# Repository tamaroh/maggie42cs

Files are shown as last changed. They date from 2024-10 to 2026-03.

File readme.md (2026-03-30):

# Maggie42cs

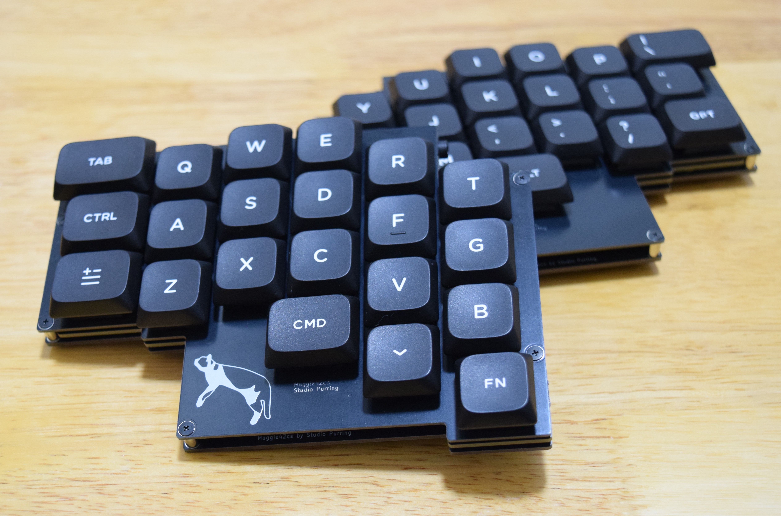
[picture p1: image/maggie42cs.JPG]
top image

Maggie42csは42キー分割型の自作キーボードです。
- 左右対称カラムスタッガード
- Alice配列に似た、自然にハの字に手が配置されるデザイン
- MX Cherry 互換スイッチ、Kailh Choc v1, v2スイッチの3種に対応
- Extension キーはキーキャップセットで揃いやすい1.25U, 1.5Uに対応

## 必要なもの

| 部品名称 | 数量（両手分） | 備考 | 主な購入先 |
| ---  | --- | --- | --- |
| PCB | 1 | サポートを折って左右に分けます | |
| トッププレート | 2 | 猫のシルエットがあるのが左側 | |
| ボトムプレート | 2 | 左右の差はありません | |
| ネジ | 24 | M2 | |
| 丸スペーサー | 12 | 5mm or 7.5mm | |
| ゴム足 | 8 | | |
| スイッチソケット | 42 | Cherry MX / Kailh choc 対応のもの | [TALP KEYBOARD](https://shop.talpkeyboard.com) など |
| メカニカルスイッチ | 42 | Cherry MX / Kailh choc V1 / V2 対応* | [遊舎工房](https://shop.yushakobo.jp/collections/all-switches) など |
| キーキャップ | 1U x 33, 1.25U x 7, 1.5U x 2 | スイッチに対応したもの | [遊舎工房](https://shop.yushakobo.jp/collections/keycaps) など |
| TRSコネクター | 2 | PJ-399B-6A | [LCSC](https://www.lcsc.com/) など |
| 3.5mmオーディオケーブル | 1 | TRRS（4極）またはTRS（3極） | [TALP KEYBOARD](https://shop.talpkeyboard.com) など |
| USBケーブル | 1 | 機器側がTypeCのもの | 家電量販店など |

## 使用する工具など

- はんだ付け工具
  - こて、こて台、こて先クリーナー、はんだ線など
- 精密ドライバー

## あると便利なもの

- ピンセット
- キースイッチプラー
- キーキャッププラー
- はんだ吸い取り線または吸い取り器
- 絶縁耐熱テープ
- 
## 製作手順

1. PCBのサポート部分を折り取ります。折った部分のデコボコが気になる場合はやすりなどで削ってください。
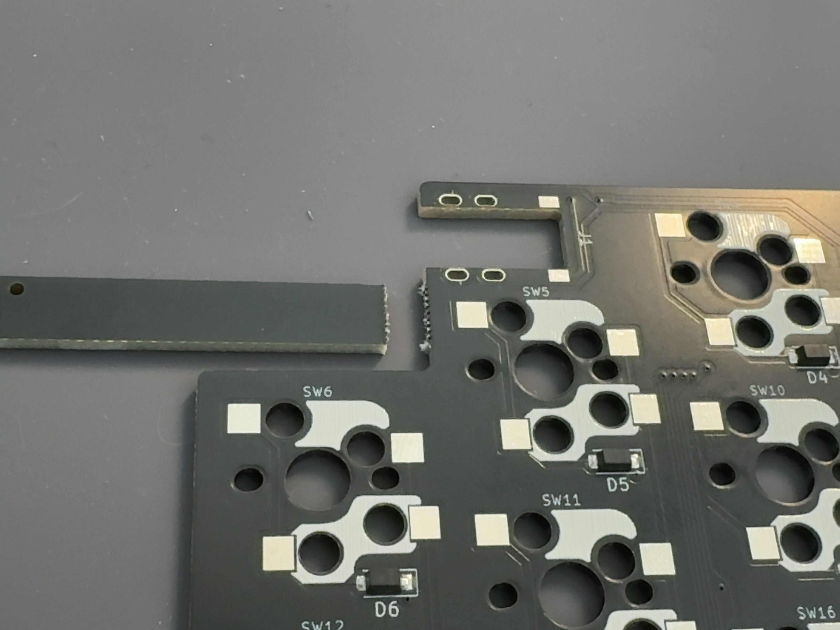
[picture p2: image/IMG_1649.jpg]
pcb
   
1. ソケットをはんだ付けします。  
   MXスイッチ用のソケットは上側、Chocスイッチ用のソケットは下側に設置します。  
   印刷に合わせて、スイッチの穴を塞がないようにします。
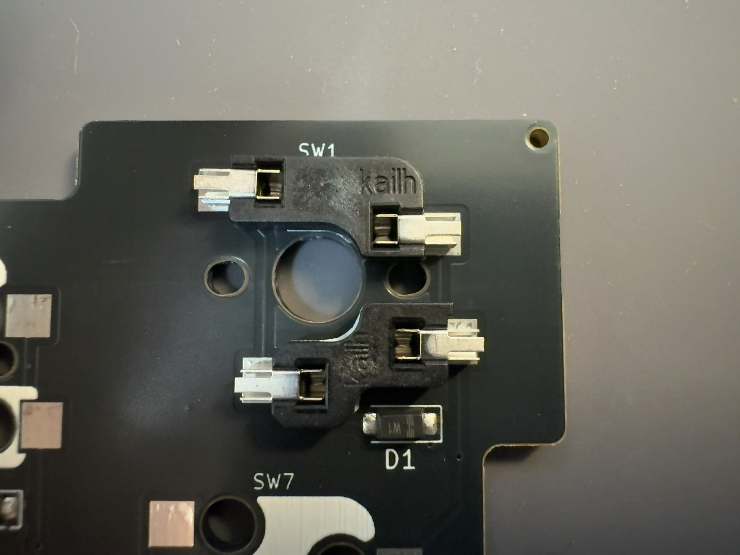
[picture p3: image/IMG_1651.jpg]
socket
   
1. TRSコネクターをはんだ付けします。  
   ずれやすいのでテープなどで固定してください。  
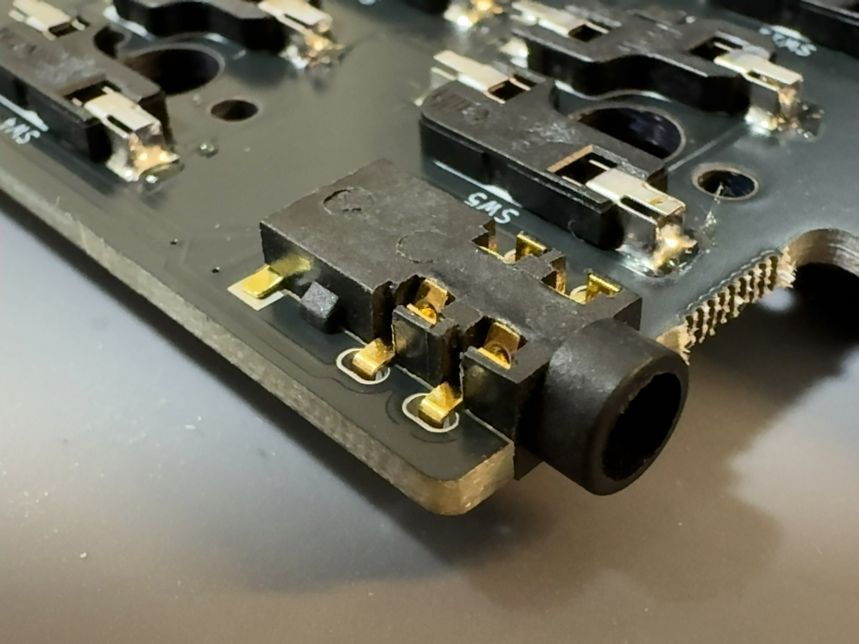
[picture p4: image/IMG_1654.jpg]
TRRS
   
1. ファームウェアのファイル（.uf2）をダウンロードします。  
   https://github.com/tamaroh/maggie42cs/releases/tag/V2.0.2
1. （片側ずつ両方とも）USBケーブルを接続して、以下のいずれかの方法で `RPI-RP2` リムーバブルドライブをマウントさせます。
   1. BOOTSELボタンを押しながら、USBケーブルを接続します。
   1. USBケーブルを接続してから、BOOTSELボタンを押しながらRESETボタンを押します。
   1. 左側はTABキー、右側はYキーを押したままUSBケーブルを接続します（キースイッチ装着済みの場合）。
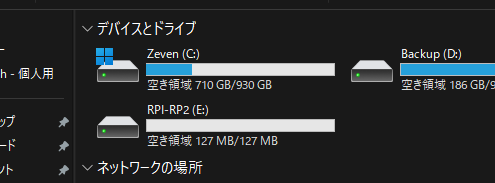
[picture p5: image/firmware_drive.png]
RPI-RP2 drive
   
1. （片側ずつ両方とも）マウントされた `RPI-RP2` ドライブ内にファームウェアのファイルをコピーして保存します。
   自動的にマウントが解除され、キーボードが再起動します。
   再起動したら、一度USBケーブルを抜いてください。
1. キースイッチを数個、先にキープレートに差し込みます。キープレートの表裏は印字以外にはありません。
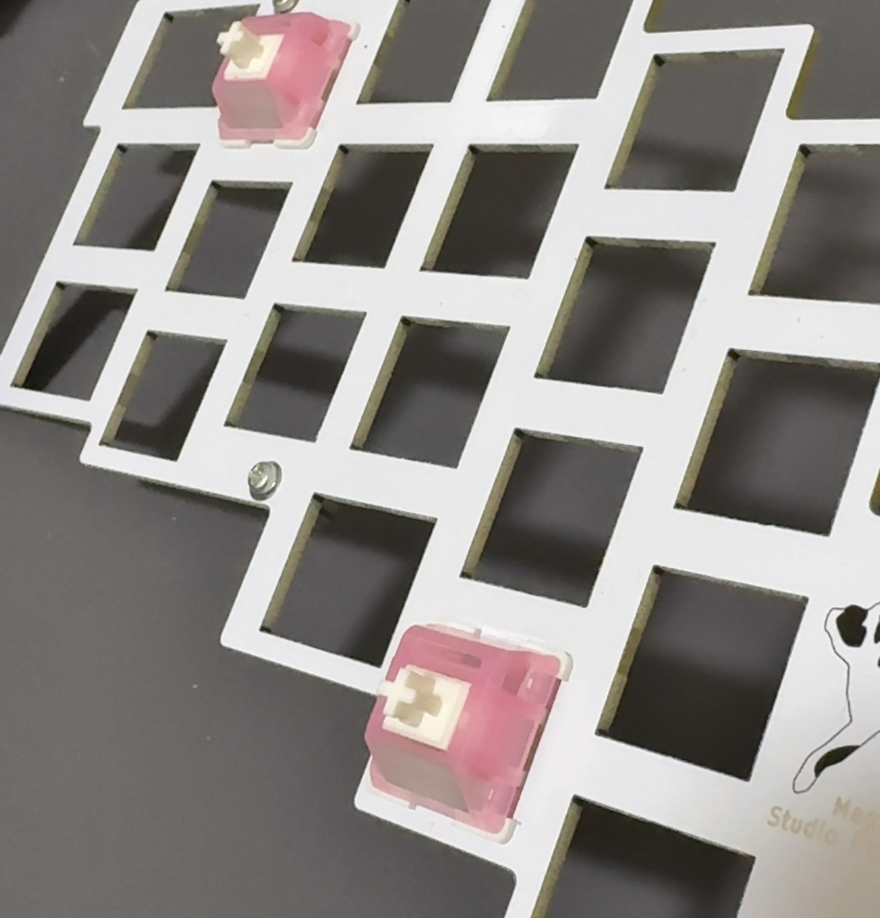
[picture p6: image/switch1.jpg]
switch1
   
1. スイッチのピンがソケットに合うように上からまっすぐ抑え、基板と接続して位置を合わせます。
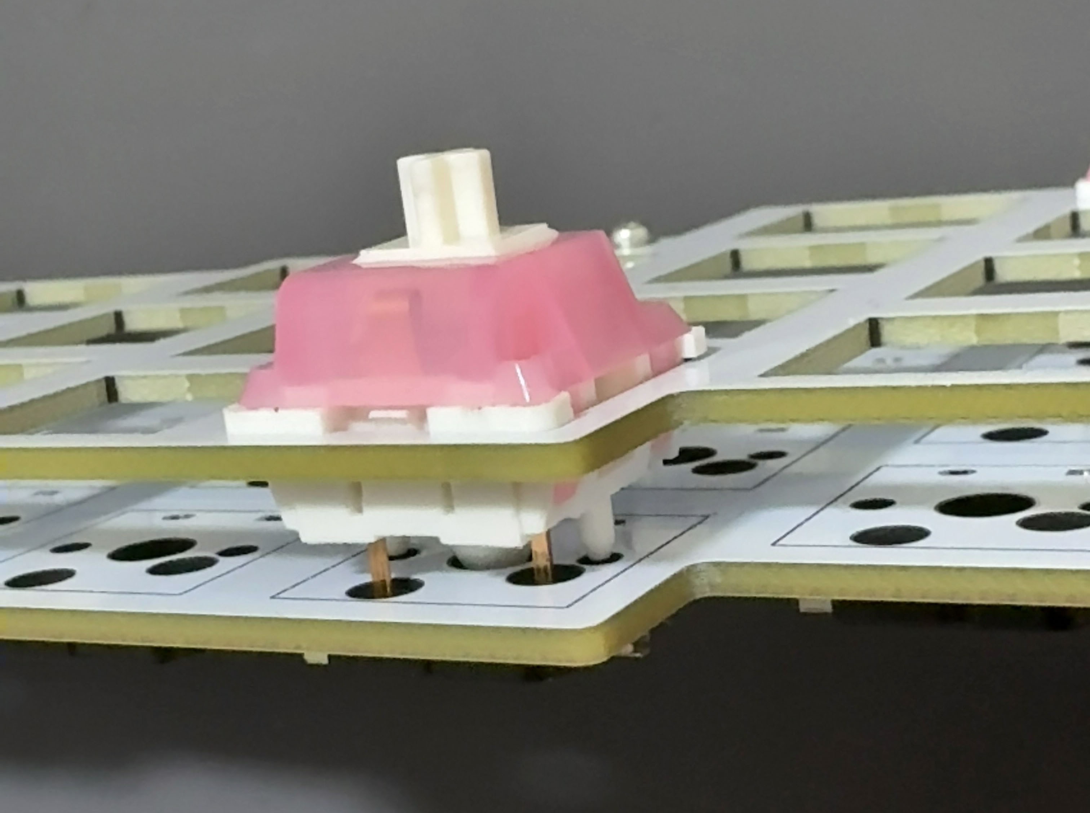
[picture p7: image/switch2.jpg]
switch2
   
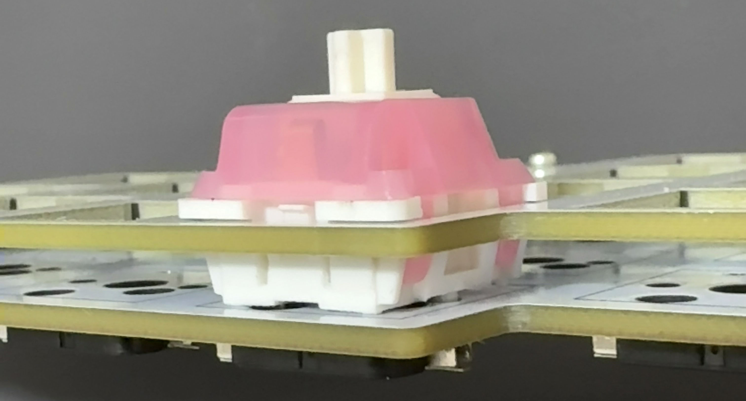
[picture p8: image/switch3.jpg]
switch3
   
1. 残りのスイッチを差し込みます。ソケットとスイッチを指で挟み込むようにして、ソケットに確実に差し込みます。
1. 基板を裏返し、ソケットからスイッチの端子の先端が見えることを確認してください。見えない場合はスイッチのピンが曲がっているか、ソケットの不良です。
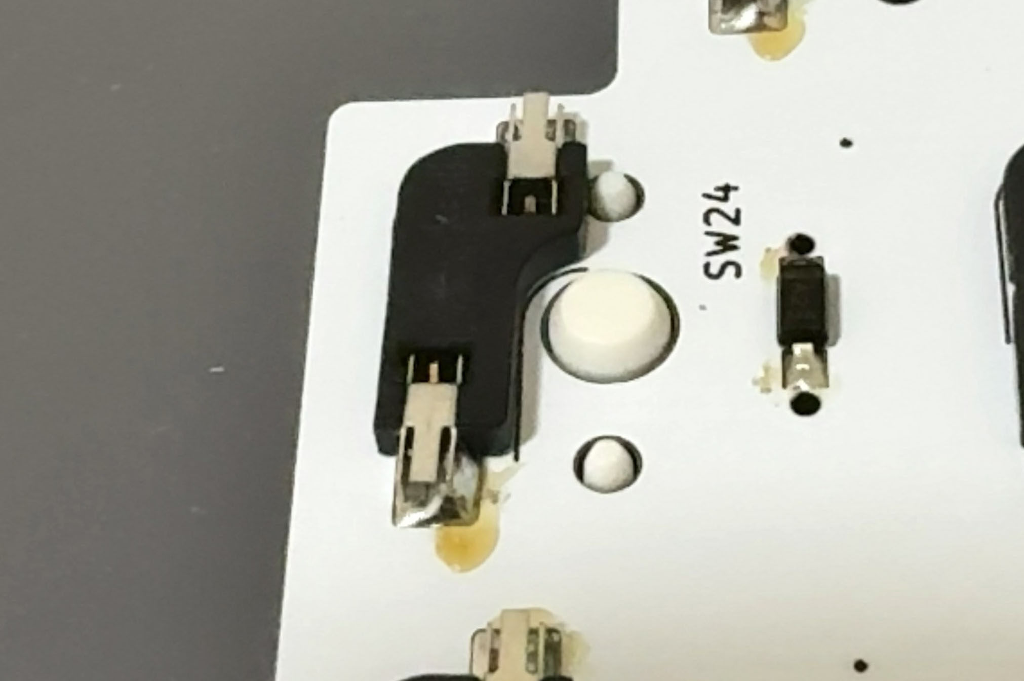
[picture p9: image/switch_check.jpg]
switch check
   
1. ネジとスペーサーをトッププレートにネジ止めします。(片側6箇所) 
1. ボトムプレートをネジ止めし、ゴム足を取り付けます。
1. キーキャップを取り付けます。
1. TRRSケーブルを接続して、できあがり

## キーマップを変更する

Maggie42は[Remap](https://remap-keys.app)によるキーマップ変更に対応しています。  
ハードウェア接続のあとJSONファイルを要求される場合は[ファームウェアと同じ場所](https://github.com/tamaroh/maggie42cs/releases/tag/V2.0.2)からダウンロードして使用してください。

## 注意事項

- 必要な手順や部品の種類・数はアップデートによって変更になる場合があります。
- 本ビルドガイドの写真の一部は製品と異なる場合があります。

## 実装の差異について

キーケット2026にて販売した一部のキットは、製作の時期により差異があります。
- 4極の3.5mmコネクターを使用しています（はんだ実装済みです）。TRS（3極）ケーブルではなくTRRS（4極）ケーブルが必要です。
- 左右でPCBの印字の色が異なります。
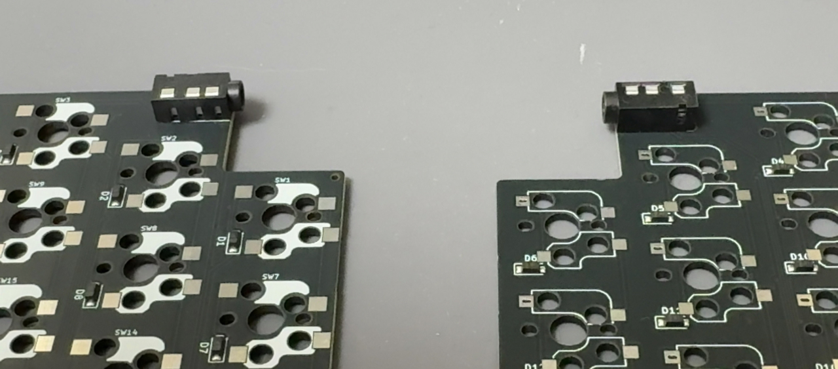
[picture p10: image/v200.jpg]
v200
  
- 手順通りのファームウェアとは異なります。書き込み済みで販売いたしましたが、再度セットアップする場合は[V2.0.0のファームウェア](https://github.com/tamaroh/maggie42cs/releases/tag/V2.0.0)を使用してください。
- Remapにアクセスした際は「maggie42csv2」と表示されます。

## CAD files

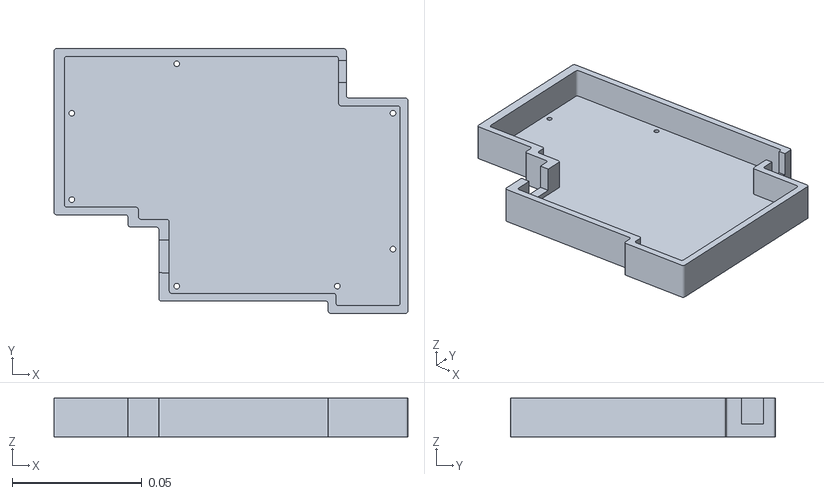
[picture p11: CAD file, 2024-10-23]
case/maggie42cs_v2_case.stl
0.137 x 0.102 x 0.015

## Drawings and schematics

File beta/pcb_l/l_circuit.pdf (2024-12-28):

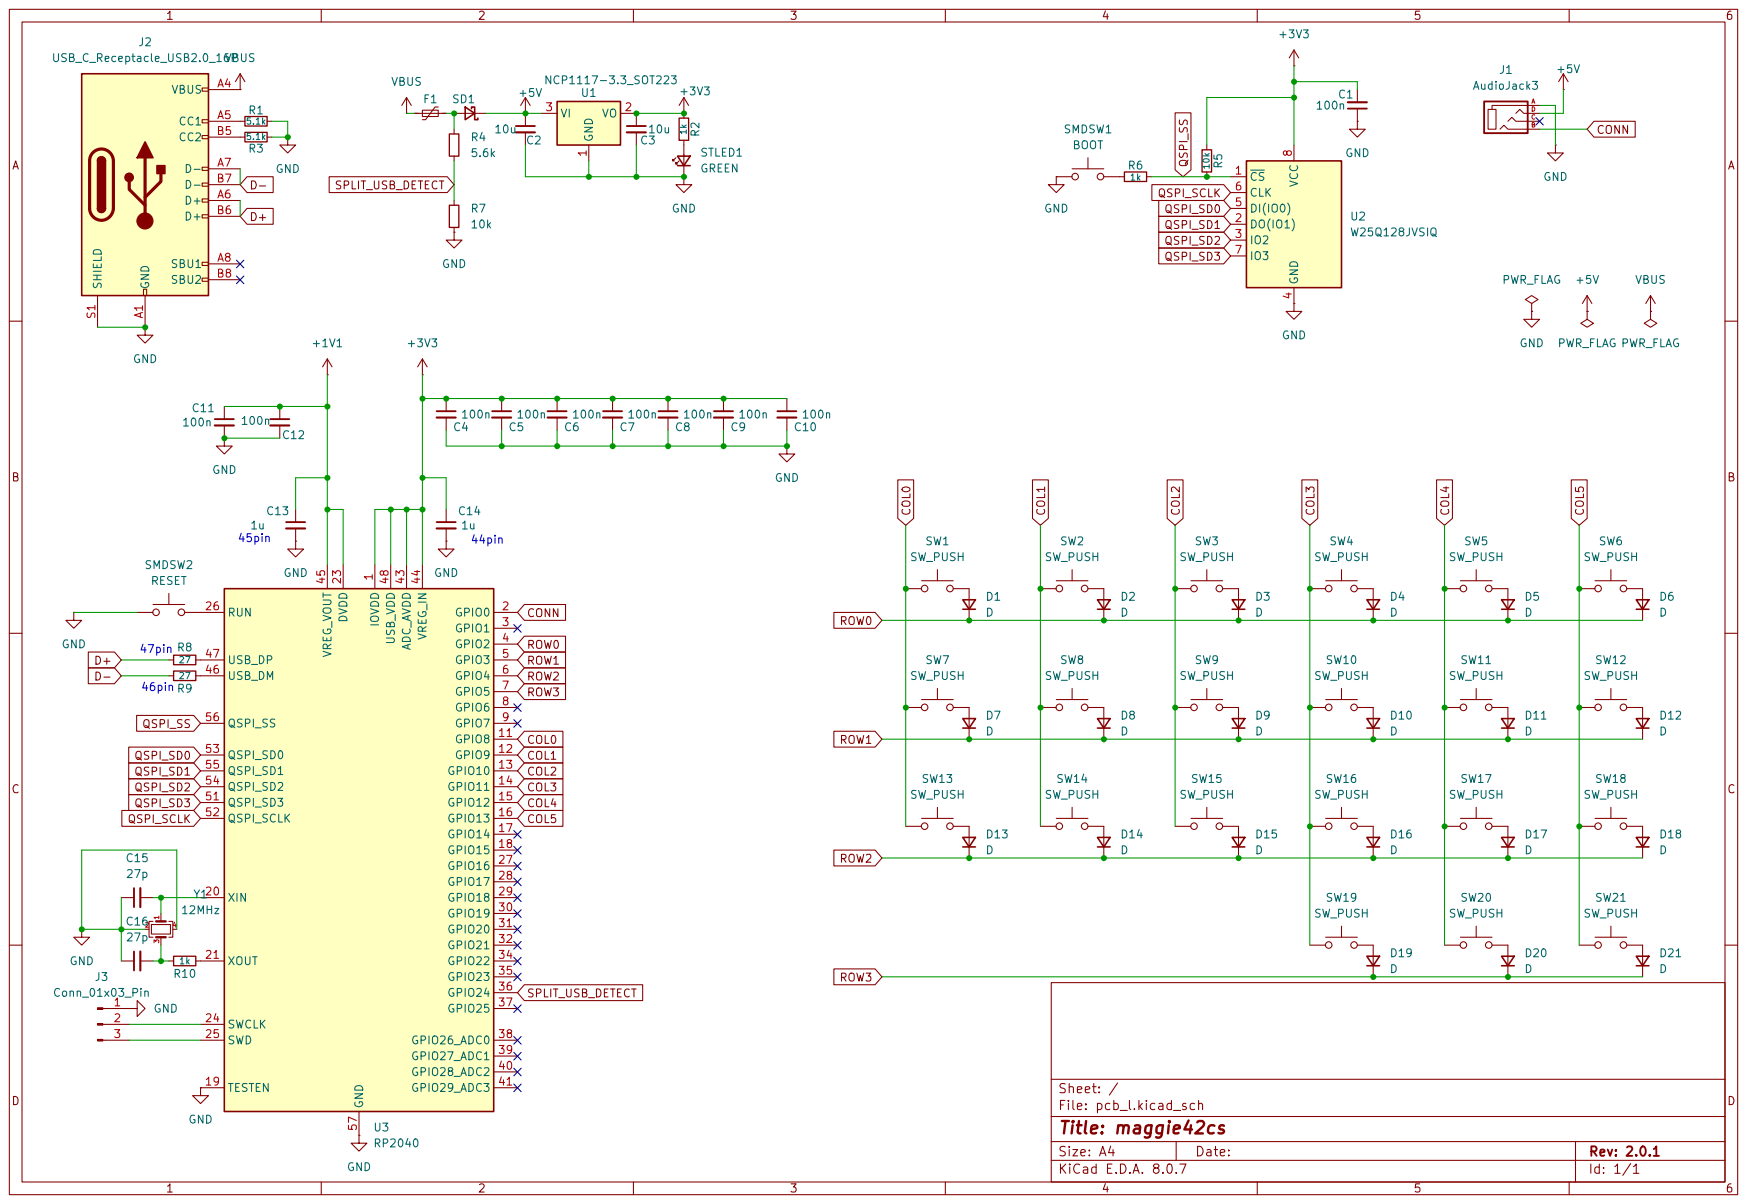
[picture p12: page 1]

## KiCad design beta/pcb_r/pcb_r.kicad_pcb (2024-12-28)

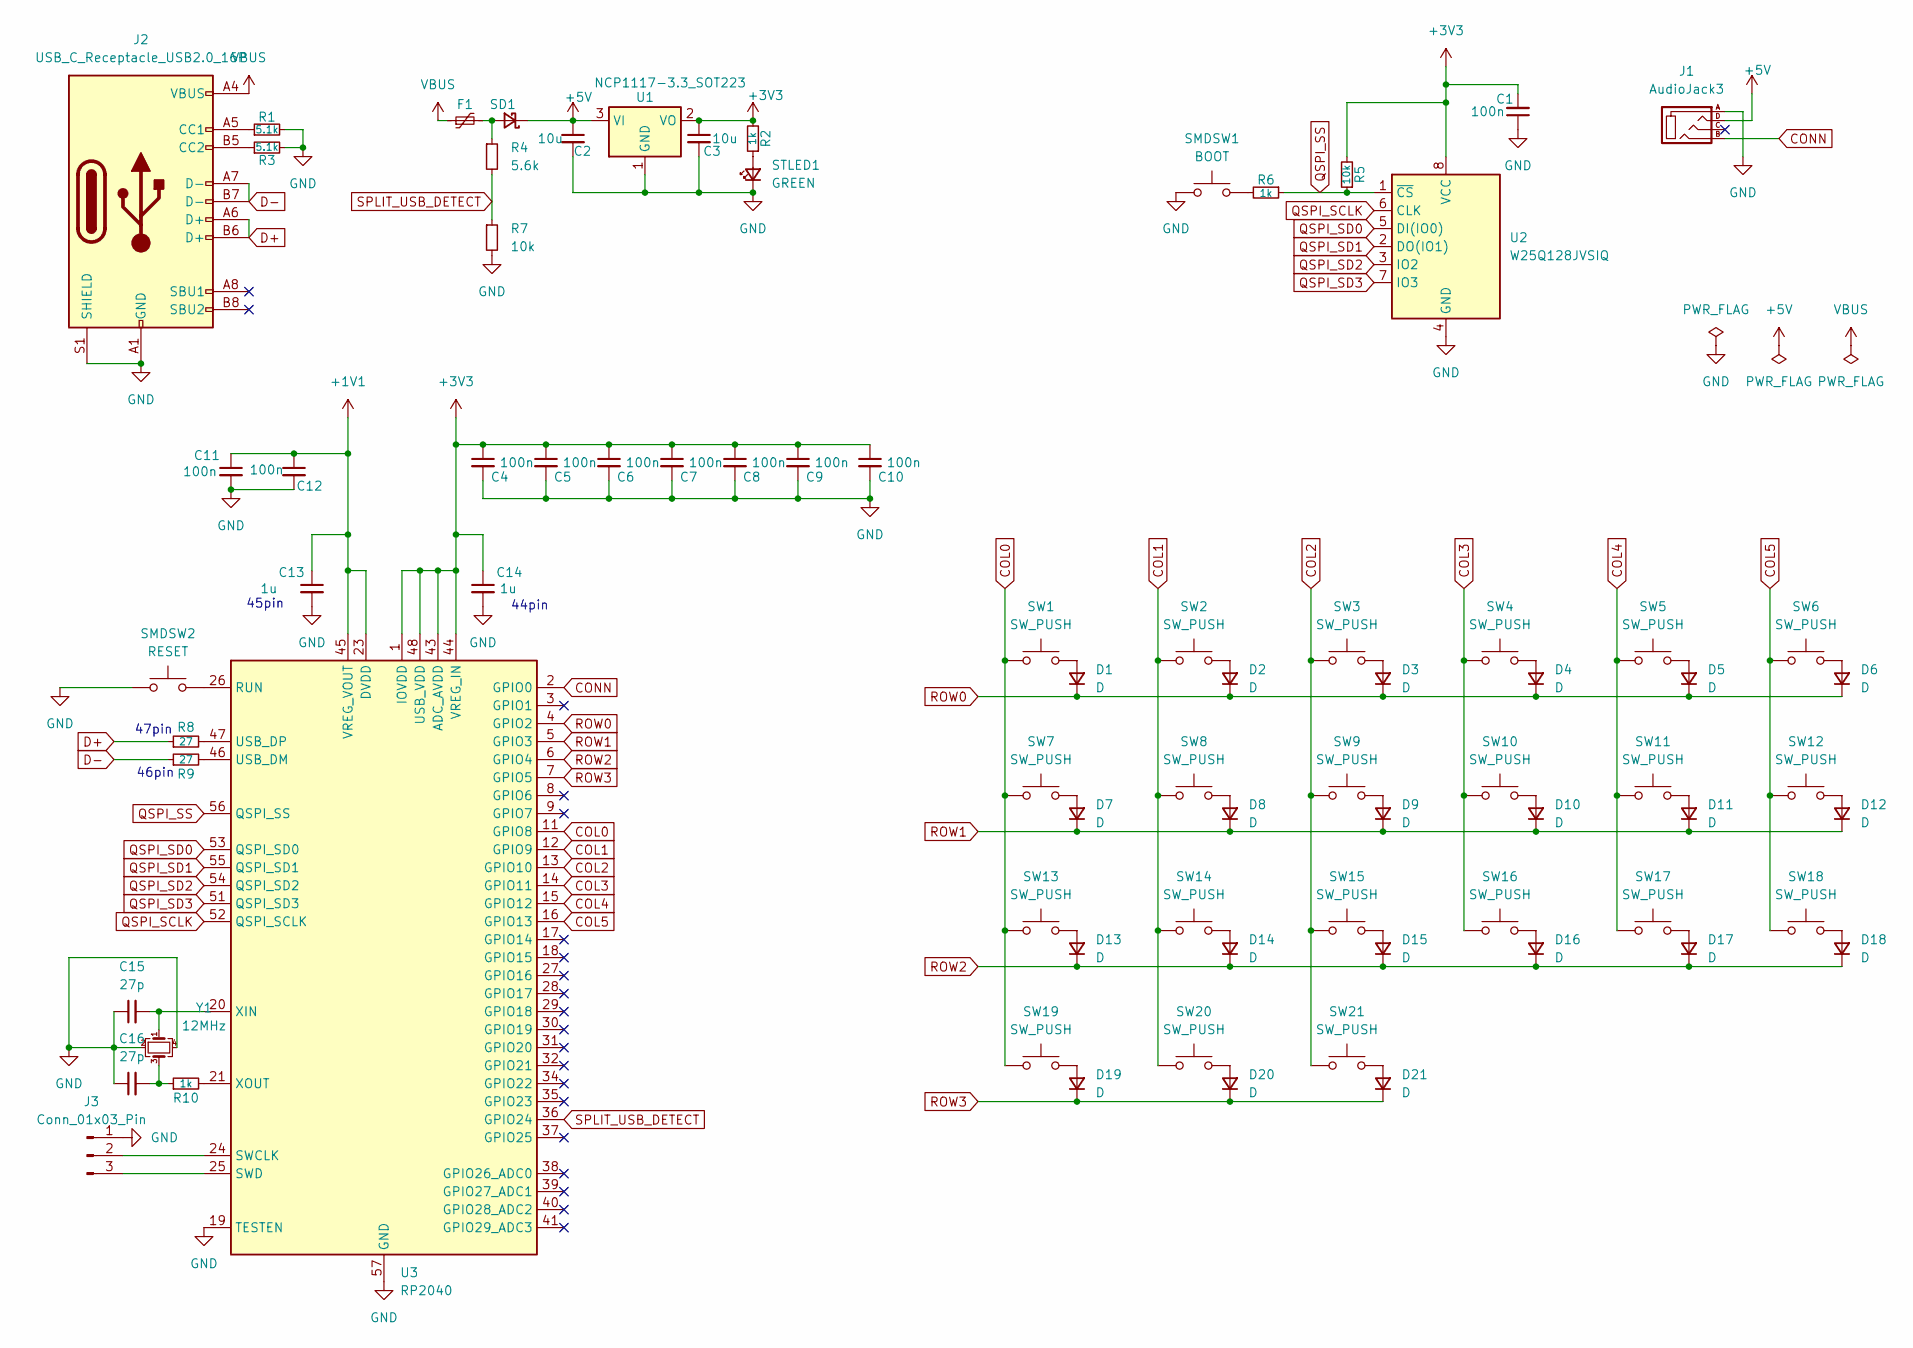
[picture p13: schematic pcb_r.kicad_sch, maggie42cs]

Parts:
C1, C4, C5, C6, C7, C8, C9, C10, C11, C12: 100n; C_0402_1005Metric; LCSC C1525
C2, C3: 10u; C_0402_1005Metric; LCSC C15525
C13, C14: 1u; C_0402_1005Metric; LCSC C52923
C15, C16: 27p; C_0402_1005Metric; LCSC C1557
D1, D2, D3, D4, D5, D6, D7, D8, D9, D10, D11, D12, D13, D14, D15, D16, D17, D18, D19, D20, D21: D; D_SOD-123; LCSC C81598
F1: Fuse_0603_1608Metric; LCSC C2757930
J1: AudioJack3; MJ-4PP-9_1side; LCSC C22459514
J2: USB_C_Receptacle_USB2.0_16P; USB_C_Receptacle_HRO_TYPE-C-31-M-12; LCSC C165948
J3: Conn_01x03_Pin; PinHeader_1x03_P1.27mm_Vertical
R1, R3: 5.1k; R_0402_1005Metric; LCSC C25905
R2, R6, R10: 1k; R_0402_1005Metric; LCSC C11702
R4: 5.6k; R_0402_1005Metric; LCSC C25908
R5, R7: 10k; R_0402_1005Metric; LCSC C25744
R8, R9: 27; R_0402_1005Metric; LCSC C25100
SD1: D_SOD-123; LCSC C8598
SMDSW1: BOOT; TS-1088R-02026; LCSC C455280
SMDSW2: RESET; TS-1088R-02026; LCSC C455280
STLED1: GREEN; LED_0402_1005Metric; LCSC C130723
SW1, SW2, SW3, SW4, SW5, SW7, SW8, SW9, SW10, SW11, SW12, SW13, SW14, SW15, SW16, SW17, SW20: SW_PUSH; keyswitch_cherrymx_choc12_hotswap_1u
SW6: SW_PUSH; keyswitch_cherrymx_choc12_hotswap_1.5u
SW18, SW19, SW21: SW_PUSH; keyswitch_cherrymx_choc12_hotswap_1.25u
U1: NCP1117-3.3_SOT223; SOT-223-3_TabPin2; LCSC C347222
U2: W25Q128JVSIQ; SOIC-8W_5.3x5.3mm_P1.27mm; LCSC C97521
U3: RP2040; QFN-56-1EP_7x7mm_P0.4mm_EP3.2x3.2mm; LCSC C2040
Y1: 12MHz; Crystal_SMD_SeikoEpson_TSX3225-4Pin_3.2x2.5mm; LCSC C91749

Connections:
+1V1: C11.1, C12.1, C13.1, U3.23 (DVDD), U3.45 (VREG_VOUT), U3.50 (DVDD)
+3V3: C1.2, C3.1, C4.1, C5.1, C6.1, C7.1, C8.1, C9.1, C10.1, C14.1, R2.2, R5.2, U1.2 (VO), U2.8 (VCC), U3.1 (IOVDD), U3.10 (IOVDD), U3.22 (IOVDD), U3.33 (IOVDD), U3.42 (IOVDD), U3.43 (ADC_AVDD), U3.44 (VREG_IN), U3.48 (USB_VDD), U3.49 (IOVDD)
+5V: C2.1, J1.D, SD1.1 (K), U1.3 (VI)
COL0: SW1.1, SW7.1, SW13.1, SW19.1, U3.11 (GPIO8)
COL1: SW2.1, SW8.1, SW14.1, SW20.1, U3.12 (GPIO9)
COL2: SW3.1, SW9.1, SW15.1, SW21.1, U3.13 (GPIO10)
COL3: SW4.1, SW10.1, SW16.1, U3.14 (GPIO11)
COL4: SW5.1, SW11.1, SW17.1, U3.15 (GPIO12)
COL5: SW6.1, SW12.1, SW18.1, U3.16 (GPIO13)
CONN: J1.B, U3.2 (GPIO0)
D+: J2.A6 (D+), J2.B6 (D+), R8.1
D-: J2.A7 (D-), J2.B7 (D-), R9.1
GND: C1.1, C2.2, C3.2, C4.2, C5.2, C6.2, C7.2, C8.2, C9.2, C10.2, C11.2, C12.2, C13.2, C14.2, C15.1, C16.1, J1.A, J2.A1 (GND), J2.A12 (GND), J2.B1 (GND), J2.B12 (GND), J2.S1 (SHIELD), J3.1, R1.2, R3.2, R7.2, SMDSW1.1, SMDSW2.1, STLED1.1 (K), U1.1 (GND), U2.4 (GND), U3.19 (TESTEN), U3.57 (GND), Y1.2, Y1.4
unnamed: C16.2, R10.1, Y1.3
unnamed: D1.2 (A), SW1.2
unnamed: D2.2 (A), SW2.2
unnamed: D3.2 (A), SW3.2
unnamed: D4.2 (A), SW4.2
unnamed: D5.2 (A), SW5.2
unnamed: D6.2 (A), SW6.2
unnamed: D7.2 (A), SW7.2
unnamed: D8.2 (A), SW8.2
unnamed: D9.2 (A), SW9.2
unnamed: D10.2 (A), SW10.2
unnamed: D11.2 (A), SW11.2
unnamed: D12.2 (A), SW12.2
unnamed: D13.2 (A), SW13.2
unnamed: D14.2 (A), SW14.2
unnamed: D15.2 (A), SW15.2
unnamed: D16.2 (A), SW16.2
unnamed: D17.2 (A), SW17.2
unnamed: D18.2 (A), SW18.2
unnamed: D19.2 (A), SW19.2
unnamed: D20.2 (A), SW20.2
unnamed: D21.2 (A), SW21.2
unnamed: J2.A5 (CC1), R1.1
unnamed: J2.B5 (CC2), R3.1
unnamed: J3.2, U3.24 (SWCLK)
unnamed: J3.3, U3.25 (SWD)
unnamed: R6.2, SMDSW1.2
unnamed: F1.2, R4.1, SD1.2 (A)
unnamed: R2.1, STLED1.2 (A)
unnamed: SMDSW2.2, U3.26 (RUN)
unnamed: R9.2, U3.46 (USB_DM)
unnamed: R8.2, U3.47 (USB_DP)
unnamed: C15.2, U3.20 (XIN), Y1.1
unnamed: R10.2, U3.21 (XOUT)
QSPI_SCLK: U2.6 (CLK), U3.52 (QSPI_SCLK)
QSPI_SD0: U2.5 (DI(IO0)), U3.53 (QSPI_SD0)
QSPI_SD1: U2.2 (DO(IO1)), U3.55 (QSPI_SD1)
QSPI_SD2: U2.3 (IO2), U3.54 (QSPI_SD2)
QSPI_SD3: U2.7 (IO3), U3.51 (QSPI_SD3)
QSPI_SS: R5.1, R6.1, U2.1 (~CS), U3.56 (QSPI_SS)
ROW0: D1.1 (K), D2.1 (K), D3.1 (K), D4.1 (K), D5.1 (K), D6.1 (K), U3.4 (GPIO2)
ROW1: D7.1 (K), D8.1 (K), D9.1 (K), D10.1 (K), D11.1 (K), D12.1 (K), U3.5 (GPIO3)
ROW2: D13.1 (K), D14.1 (K), D15.1 (K), D16.1 (K), D17.1 (K), D18.1 (K), U3.6 (GPIO4)
ROW3: D19.1 (K), D20.1 (K), D21.1 (K), U3.7 (GPIO5)
SPLIT_USB_DETECT: R4.2, R7.1, U3.36 (GPIO24)
VBUS: F1.1, J2.A4 (VBUS), J2.A9 (VBUS), J2.B4 (VBUS), J2.B9 (VBUS)

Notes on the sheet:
47pin
45pin
44pin
46pin

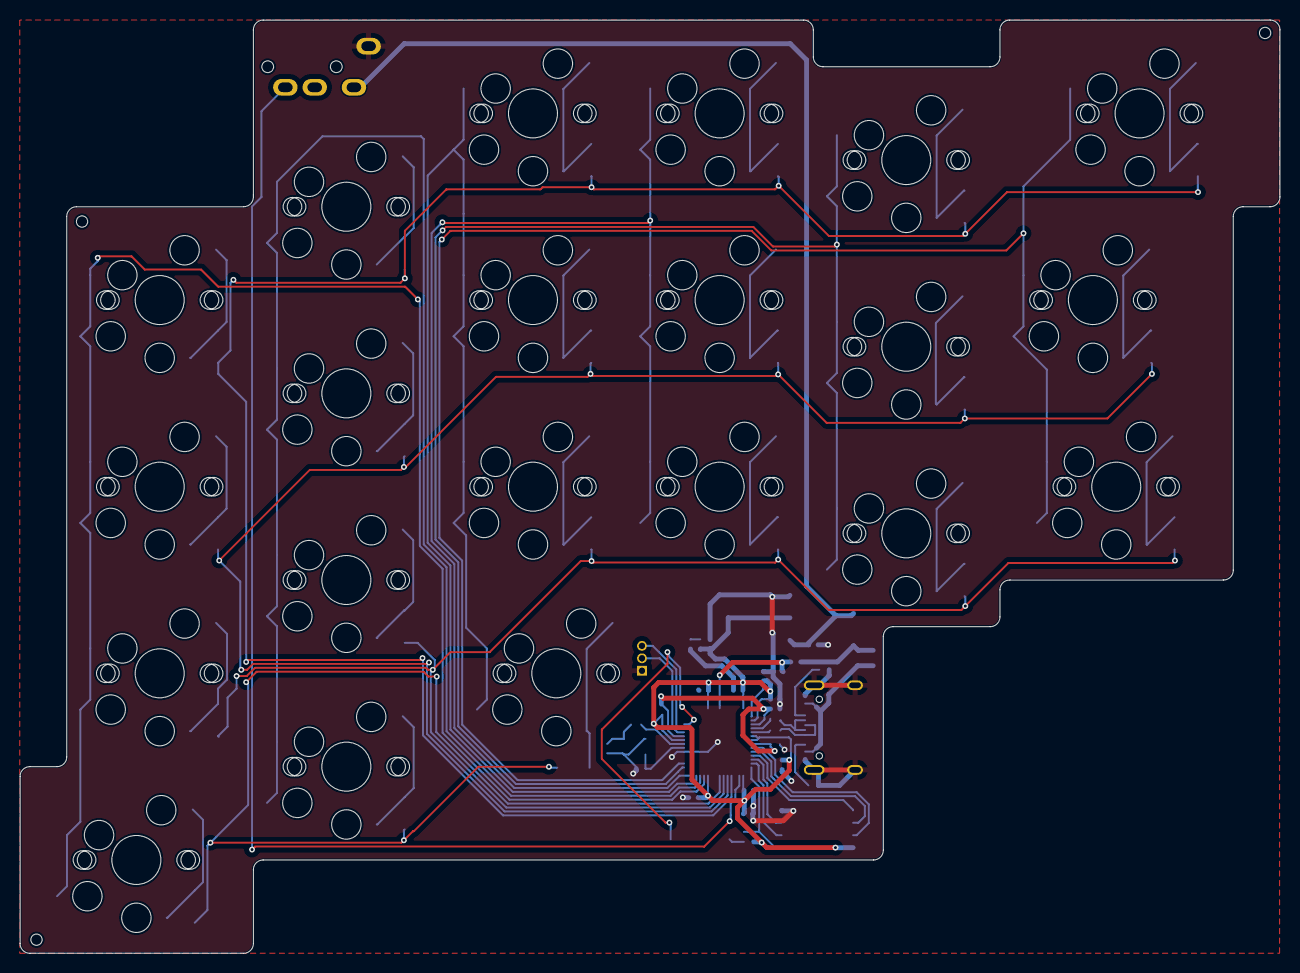
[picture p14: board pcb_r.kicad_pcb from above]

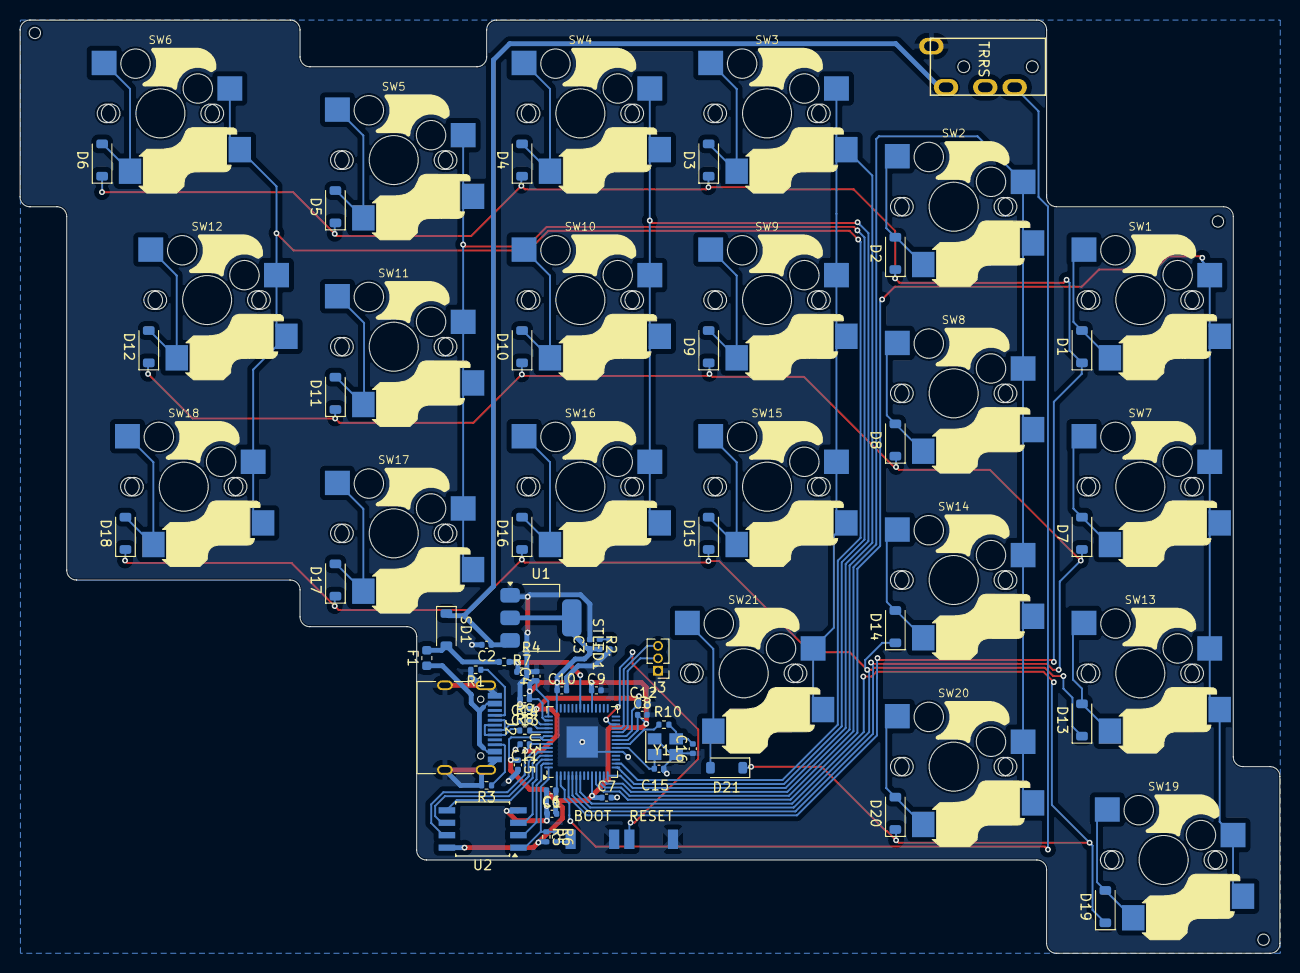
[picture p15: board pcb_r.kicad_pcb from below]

Board: 2 copper layers, 128.6 x 95.2 mm, 80 parts (80 on the bottom side), 59 nets.

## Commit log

2023-12-27 added gitignore for kicad
2023-12-27 created pcbs
    [maggie42rs_pcb.kicad_sch, pcb_l.kicad_sch, pcb_r.kicad_sch]
2024-10-23 added v2.0.0, failed
    [bottom.kicad_pcb, left.kicad_sch, left_switch.kicad_sch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]
2024-10-25 create v2 init, v2.json for VIA
    [left.kicad_sch, pcb.kicad_sch, right.kicad_sch]
2024-11-10 fixed pid
2024-11-19 1.1: create garbar files, 2.0: create left pcb
    [bottomplate_1_1.kicad_pcb, keyplate_1_1.kicad_pcb, keyplate_l.kicad_pcb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]
2024-11-23 update: 2.0.1_pcb_l
    [pcb_l.kicad_sch, pcb_r.kicad_sch]
2024-12-28 WIP: v2 refactoring
    [left.kicad_sch, pcb_r.kicad_sch, right.kicad_sch]
2024-12-28 refactor: change folder name, old data is no maggie42cs0
    [bottom.kicad_pcb, bottomplate.kicad_pcb, bottomplate_1_1.kicad_pcb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]
2025-01-11 wip: layout
    [key_layout.kicad_sch, pcb.kicad_sch]
2025-02-17 add: pcb and plate garber files
    [bottom.kicad_pcb, pcb.kicad_sch, topplate.kicad_pcb]
2026-03-24 add production files
    [pcb-B_Cu.gbl, pcb-B_Mask.gbs, pcb-B_Paste.gbp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]
2026-03-30 add description about old connector
